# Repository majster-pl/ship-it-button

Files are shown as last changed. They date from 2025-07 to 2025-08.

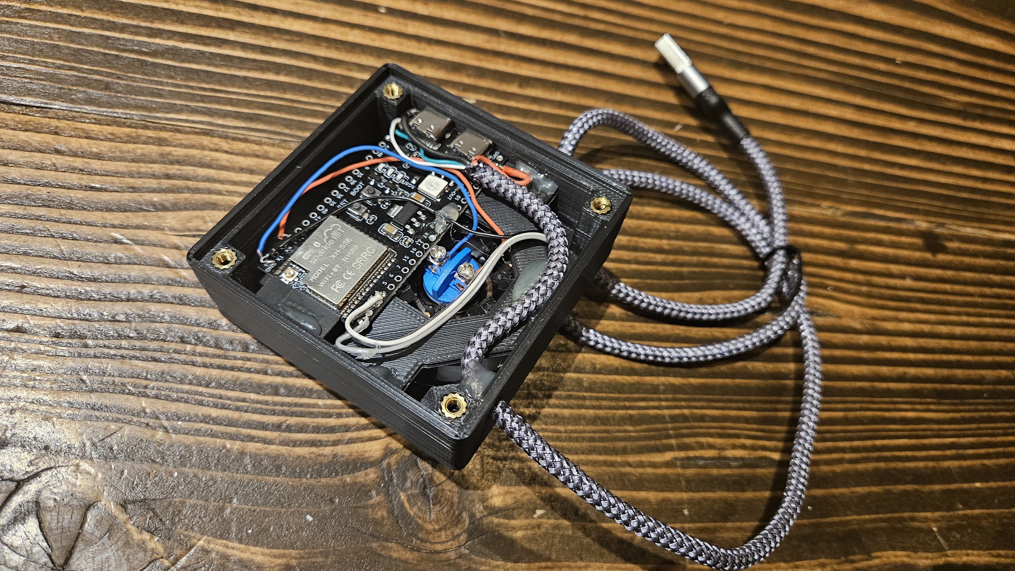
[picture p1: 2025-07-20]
images/shipit-inside_2.jpg

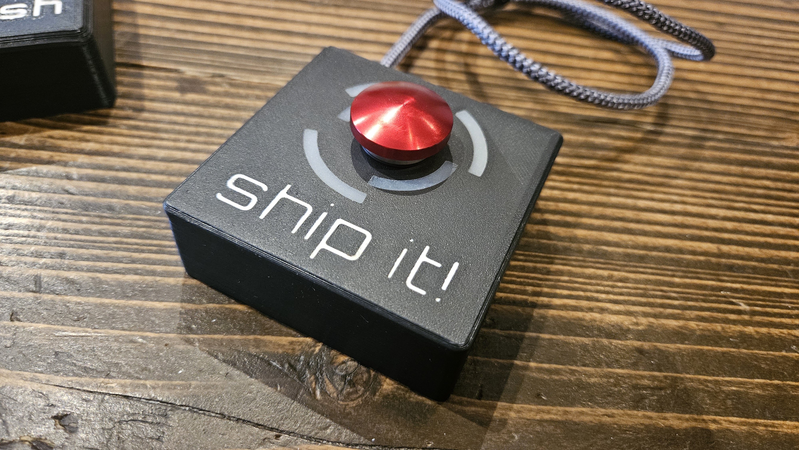
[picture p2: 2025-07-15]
images/shipit-front.jpg

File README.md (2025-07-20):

## 🚀 Ship It! Button

A 3D-printed USB device designed for dramatic deployments.



## Ship It Box
Ship It Box

## Inside (ESP32-S3)
Inside

## Back Cover
Back Cover

## Back Cover with pads
shipit-back_3

## Start up animation
https://github.com/user-attachments/assets/f34a8139-bcb4-40e1-bdf6-34d7109cfc78

## On button pressed animation
https://github.com/user-attachments/assets/eb8da8be-4c95-493a-8b3f-b23c512ba0db

## Schematic


### ✨ Features

- **Black Box Design**: A matte 3D-printed enclosure with a centered button and hidden RGB LEDs around it.
- **"Ship it!" Engraving**: Stylish engraving right under the button for extra flair.
- **USB Plug & Play**: Acts as a keyboard when connected via USB.

### 🔧 🚥

| Action | Result |
|---|---|
| Plug in USB | LEDs perform a **red breathing animation**, then fade to black (standby) 🚥 |
| Press the button | Triggers the **OBC launch animation** (purple LED chase effect), then sends `:ship: ship it! :rocket:` (**🚢 ship it! 🚀**) as keyboard input followed by `Enter` - ideal for Slack message ✅ |
| Standby Mode | LEDs stay off until the next button press or randomly every 1-20min red breathing animation with random number of breaths will kick in 🙂 |

### 🌀 Animations

- **Breathing Animation**: Gentle red glow mimicking breathing, plays once at start or in intervals.
- **OBC Animation**: Purple LED "chase" with acceleration, cruise, and deceleration phases.
- **Keyboard Input**: Automatically sends the message using USB HID after the animation.

### 🔩 Hardware

- **Microcontroller**: ESP32-S3
- **LEDs**: 8 × WS2812B RGB LEDs (You can get premade rings by I've made this from scratch by cutting strip into pieces and soldering together 🤦)
- **Button**: Red anodized aluminum push button (momentary) I bought few on [AliExpress](https://a.aliexpress.com/_EvYcgQm)
- **Power/Data**: Standard USB cable (USB HID capable)
- **Enclosure**: Custom 3D-printed case with hidden LEDs and center-mounted button
- **Other Materials**:  
  - *Hot glue* — to fill the gaps around the button  
  - *White silicone* — to fill the "ship it!" text  
  - *M2.5 screws & inserts* — to secure the back cover  
  - *12mm × 2mm rubber pads* — to cover the screws and reduce sliding

### 🧱 3D Model

- Designed using [Tinkercad](https://www.tinkercad.com/)
- `.stl` files included in this repository
- Printed on a **Creality Ender 3 V3 SE** 3D printer using PLA

### 🧠 Built With

- [FastLED](https://github.com/FastLED/FastLED) – RGB LED control
- USB HID keyboard emulation
- Randomized animation patterns for variety

### 🛠️ Code

- Written in **C/C++** for microcontrollers (Arduino-style).
- Developed with some help from **[ChatGPT](https://openai.com/chatgpt)** for animation logic and optimization.

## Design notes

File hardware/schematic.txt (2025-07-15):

   +---------------------+
   |     USB Cable       |
   |---------------------|
   |  Red (5V)  -----------+--------------------+
   |  Black (GND) ---------+                    |
   |  Green (D+) ----------> GPIO20 (D+)        |
   |  White (D-) ----------> GPIO19 (D-)        |
   +--------------------------------------------+
                                                  
                      +--------------------+     
                      |    ESP32-S3 Dev    |     
                      |--------------------|     
                      |                    |     
                      | GPIO1  <-----------+---[ BUTTON ]--- GND
                      | GPIO4   -----------> LED DIN
                      | 3V3     --------+--> LED VCC
                      | GND     --------+--> LED GND
                      |                    |
                      +--------------------+

                             +------------------+
                             |   WS2812B LED    |
                             |    Strip (x8)    |
                             |------------------|
                             | VCC <------------+
                             | GND <------------+
                             | DIN <------------ GPIO4
                             +------------------+

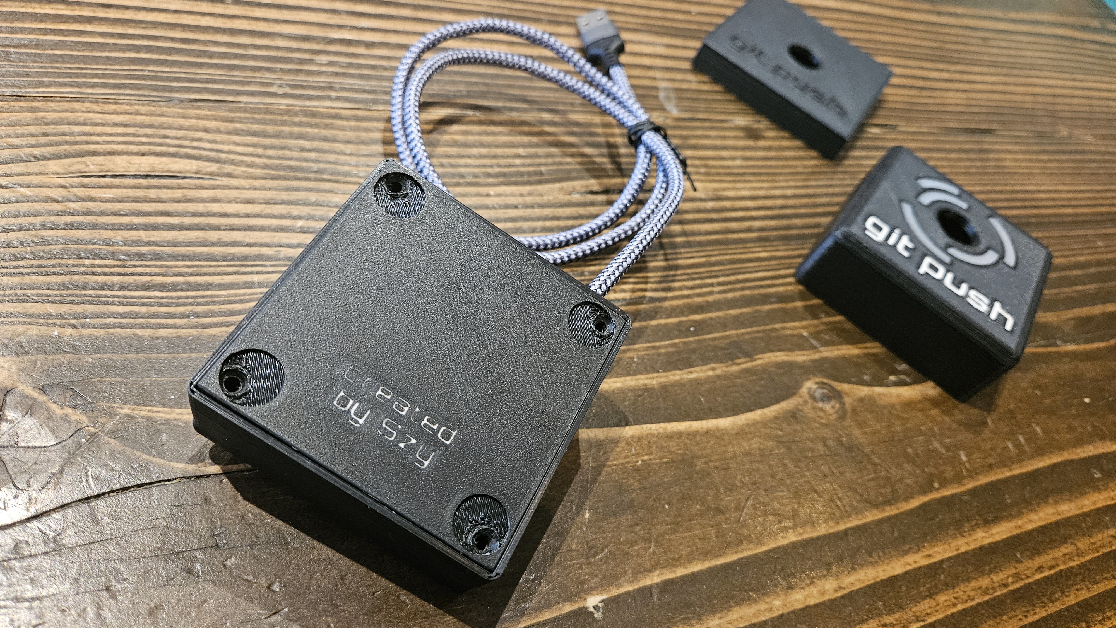
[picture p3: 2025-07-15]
images/shipit-back.jpg

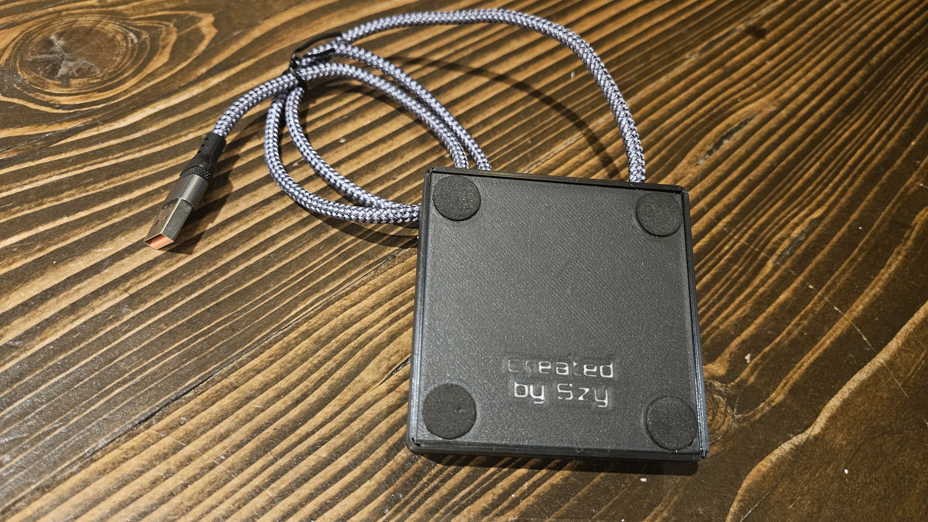
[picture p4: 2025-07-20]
images/shipit-back_3.jpg

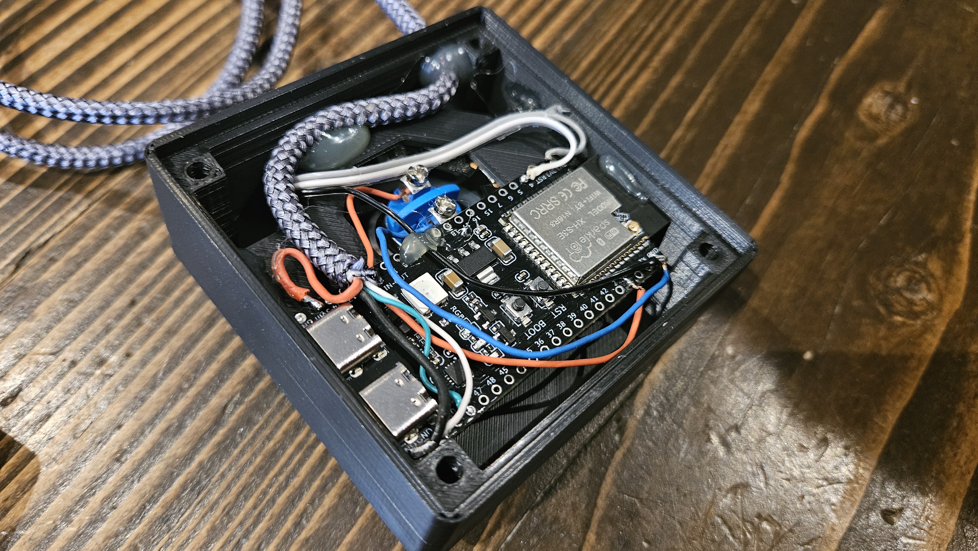
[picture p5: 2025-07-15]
images/shipit-inside.jpg

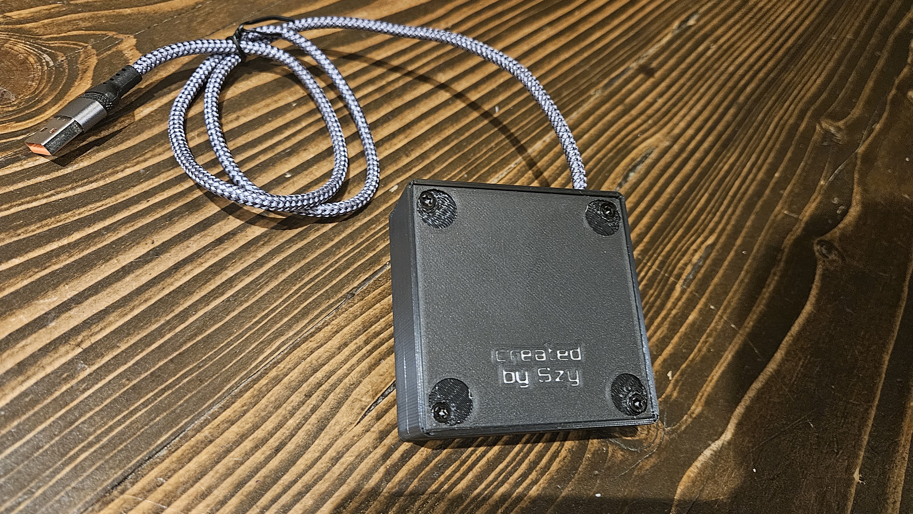
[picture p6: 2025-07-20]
images/shipit-back_2.jpg

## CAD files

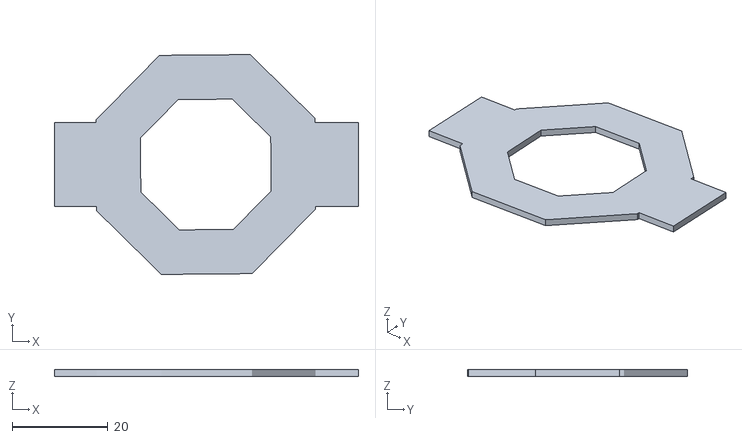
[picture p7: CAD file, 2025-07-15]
hardware/ship_it_button_led_bracket.stl
63.6 x 46.0 x 1.40

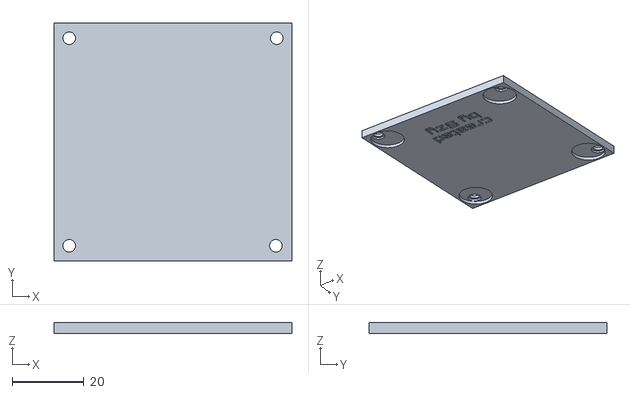
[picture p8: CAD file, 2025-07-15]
hardware/ship_it_button_cover.stl
66.5 x 66.5 x 3.00

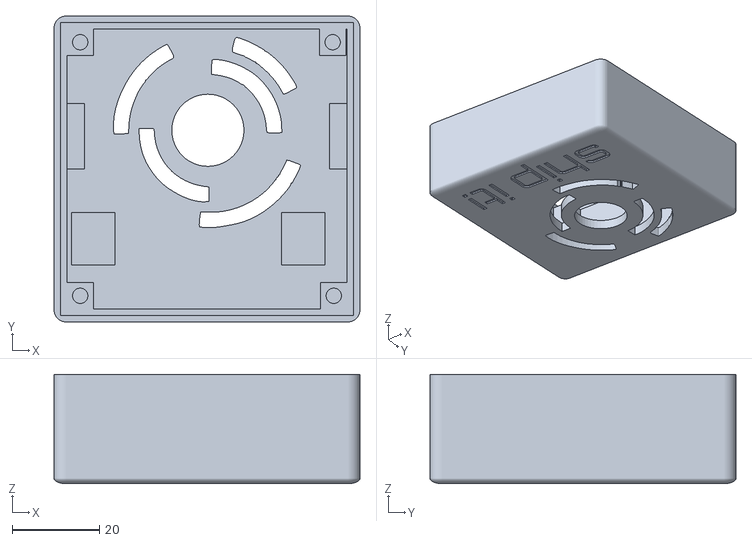
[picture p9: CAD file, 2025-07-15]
hardware/ship_it_button_box.stl
70.0 x 70.0 x 25.0

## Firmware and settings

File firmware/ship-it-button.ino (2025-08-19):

 /*
 * Ship It! Button
 *
 * Hardware: ESP32-S3, 8x WS2812B, USB HID
 * Designed and 3D modeled in Tinkercad
 * STL files and build instructions: see README.md
 * 
 * Libraries used:
 * - FastLED
 * - USBHIDKeyboard (ESP32-S3 compatible)
 * 
 * Developed with help from ChatGPT (OpenAI)
 * 
 * Copyright (C) 2025 Szymon Waliczek <szymon@waliczek.org>
 *
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
 * You should have received a copy of the GNU General Public License
 * along with this program. If not, see <https://www.gnu.org/licenses/>.
 */


#include <FastLED.h>
#include "USB.h"
#include "USBHIDKeyboard.h"

// === LED Config ===
#define LED_PIN        4
#define NUM_LEDS       8
#define BRIGHTNESS     100
#define LED_TYPE       WS2812B
#define COLOR_ORDER    GRB

CRGB leds[NUM_LEDS];

// === Button Config ===
#define BUTTON_PIN     1

// === USB Keyboard ===
USBHIDKeyboard Keyboard;

// === State ===
bool animationTriggered = false;
bool lastButtonState = HIGH;
bool currentButtonState = LOW;
bool initialAnimationPlayed = false;

void setup() {
  randomSeed(analogRead(A0));

  FastLED.addLeds<LED_TYPE, LED_PIN, COLOR_ORDER>(leds, NUM_LEDS);
  pinMode(BUTTON_PIN, INPUT_PULLUP);
  turnOffLeds();

  delay(2000); // Initial delay before animations

  Keyboard.begin();
  USB.begin();
}

void loop() {
  // Check for button press
  currentButtonState = digitalRead(BUTTON_PIN);
  if (lastButtonState == HIGH && currentButtonState == LOW) {
    animationTriggered = true;
  }
  lastButtonState = currentButtonState;

  if (animationTriggered) {
    animationTriggered = false;
    animationOBC();
    turnOffLeds();
  } else {
    int standbySeconds = getRandom(60, 60 * 20);
    if (!initialAnimationPlayed) {
      breathingAnimation(getRandom(1, 2));
      standByInSeconds(standbySeconds);
    } else {
      standByInSeconds(standbySeconds);
      breathingAnimation(getRandom(1, 2));
    }
    initialAnimationPlayed = true;
  }
}

// === Helper Functions ===

bool checkIfButtonPressed() {
  currentButtonState = digitalRead(BUTTON_PIN);
  if (lastButtonState == HIGH && currentButtonState == LOW) {
    animationTriggered = true;
    turnOffLeds();
    return true;
  }
  return false;
}

void standByInSeconds(int seconds) {
  for (int i = 0; i < seconds * 1000; i += 100) {
    if (checkIfButtonPressed()) break;
    delay(100);
  }
}

void turnOffLeds() {
  fill_solid(leds, NUM_LEDS, CRGB::Black);
  FastLED.show();
}

int getRandom(int min, int max) {
  return rand() % (max - min + 1) + min;
}

float getRandomFloat(float min, float max) {
  return min + ((float)rand() / RAND_MAX) * (max - min);
}

void updateChase(uint8_t &pos, unsigned long &lastUpdate, float delayTime) {
  if (millis() - lastUpdate >= delayTime) {
    lastUpdate = millis();
    fadeToBlackBy(leds, NUM_LEDS, 100);
    leds[pos] = CRGB::Purple;
    FastLED.show();
    pos = (pos + 1) % NUM_LEDS;
  }
}

void shipItCommand() {
  Keyboard.print(":ship: ship it! :rocket:");
  delay(200);
  Keyboard.write(KEY_RETURN); 
  delay(10);
  Keyboard.releaseAll();
}

void animationOBC() {
  // === Timing ===
  const unsigned long fadeInTime   = 300;
  const unsigned long accelTime    = 700;
  const unsigned long cruiseTime   = 1500;
  const unsigned long decelTime    = 2000;
  const unsigned long fadeOutTime  = 2000;
  const float startDelay           = 200;
  const float maxSpeedDelay        = 15;

  uint8_t pos = random(0, NUM_LEDS);
  unsigned long lastUpdate = 0;
  float currentDelay = startDelay;

  // --- Phase 0: Fade In ---
  unsigned long phaseStart = millis();
  while (millis() - phaseStart < fadeInTime) {
    float t = (float)(millis() - phaseStart) / fadeInTime;
    FastLED.setBrightness((uint8_t)(t * BRIGHTNESS));
    updateChase(pos, lastUpdate, startDelay);
  }

  // --- Phase 1: Acceleration ---
  phaseStart = millis();
  while (millis() - phaseStart < accelTime) {
    float t = (float)(millis() - phaseStart) / accelTime;
    currentDelay = startDelay - ((1 - cos(t * PI)) / 2.0f) * (startDelay - maxSpeedDelay);
    updateChase(pos, lastUpdate, currentDelay);
  }

  // --- Ship It! ---
  shipItCommand();

  // --- Phase 2: Cruise ---
  phaseStart = millis();
  while (millis() - phaseStart < cruiseTime) {
    updateChase(pos, lastUpdate, maxSpeedDelay);
  }

  // --- Phase 3: Deceleration ---
  phaseStart = millis();
  while (millis() - phaseStart < decelTime) {
    float t = (float)(millis() - phaseStart) / decelTime;
    currentDelay = maxSpeedDelay + ((1 - cos(t * PI)) / 2.0f) * (startDelay - maxSpeedDelay);
    updateChase(pos, lastUpdate, currentDelay);
  }

  delay(800); // Pause before fade out

  // --- Phase 4: Fade Out ---
  phaseStart = millis();
  while (millis() - phaseStart < fadeOutTime) {
    fadeToBlackBy(leds, NUM_LEDS, 20);
    FastLED.show();
    delay(25);
  }
}

void fadeOutLeds(uint8_t startBrightness, unsigned long durationMillis) {
  const unsigned long stepDelay = 5;
  unsigned long steps = durationMillis / stepDelay;
  if (steps == 0) steps = 1;

  for (unsigned long i = 0; i < steps; i++) {
    uint8_t brightness = map(steps - i, 0, steps, 0, startBrightness);
    FastLED.setBrightness(brightness);
    FastLED.show();
    if (checkIfButtonPressed()) break;
    delay(stepDelay);
  }

  FastLED.setBrightness(0);
  turnOffLeds();
}

void breathingAnimation(uint8_t breathCount) {
  const unsigned long breathDuration = 2500;
  const uint8_t breathMaxBrightness = 40;
  const float minBrightnessFactor = 0.15f;
  const float mainBrightnessFactor = getRandomFloat(0.3, 1);
  const unsigned long fadeInTime = 300;

  // Fade in to min brightness
  unsigned long fadeStart = millis();
  uint8_t targetMinBrightness = minBrightnessFactor * breathMaxBrightness;

  while (millis() - fadeStart < fadeInTime) {
    uint8_t brightness = map(millis() - fadeStart, 0, fadeInTime, 0, targetMinBrightness);
    FastLED.setBrightness(brightness * mainBrightnessFactor);
    fill_solid(leds, NUM_LEDS, CRGB::Red);
    FastLED.show();
    if (checkIfButtonPressed()) return;
    delay(20);
  }

  // Main breathing loop
  unsigned long totalDuration = breathCount * breathDuration;
  unsigned long startTime = millis();
  uint8_t currentBrightness = 0;

  while (millis() - startTime < totalDuration) {
    float t = (float)((millis() - startTime) % breathDuration) / breathDuration;
    float brightnessFactor = minBrightnessFactor + ((1 - cos(t * 2 * PI)) / 2.0f) * (1 - minBrightnessFactor);
    currentBrightness = brightnessFactor * breathMaxBrightness * mainBrightnessFactor;

    FastLED.setBrightness(currentBrightness);
    fill_solid(leds, NUM_LEDS, CRGB::Red);
    FastLED.show();

    if (checkIfButtonPressed()) return;
  }

  fadeOutLeds(currentBrightness, 800);
  turnOffLeds();
}

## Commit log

2025-07-15 add printer and 3d models details to readme
2025-07-15 Add schematic
2025-07-15 Add hardware firmware images to the project
    [ship_it_button_box.stl, ship_it_button_cover.stl, ship_it_button_led_bracket.stl]
2025-07-15 Add other materials to README.md file
2025-08-19 fix(slack): ensure emojis are properly rendered in messages
    [ship-it-button.ino]

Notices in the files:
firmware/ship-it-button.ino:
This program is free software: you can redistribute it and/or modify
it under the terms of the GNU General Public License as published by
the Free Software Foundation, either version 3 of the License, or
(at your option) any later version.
